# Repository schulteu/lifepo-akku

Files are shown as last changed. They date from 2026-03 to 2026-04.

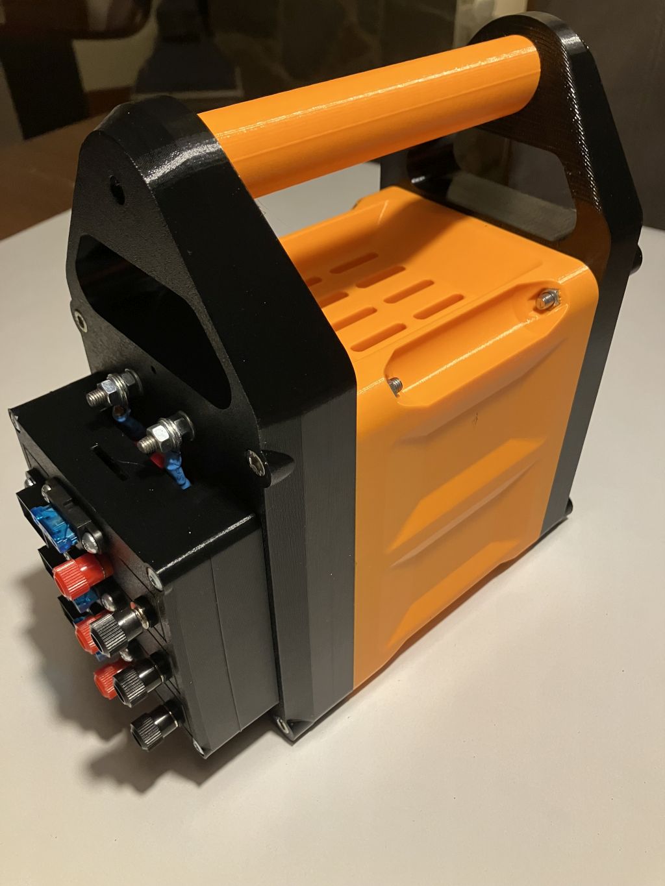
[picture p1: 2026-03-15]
Bilder/IMG_0235.JPG

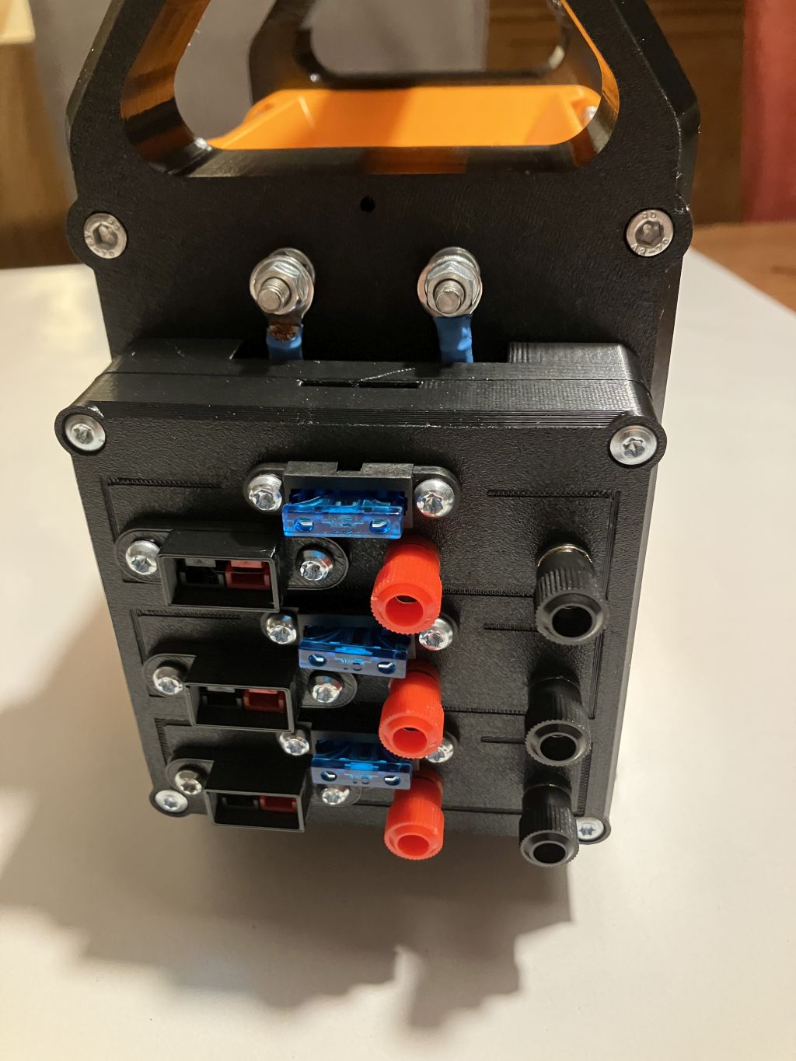
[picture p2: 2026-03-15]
Bilder/IMG_0234.JPG

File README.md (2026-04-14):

# LiFePo4-Akku 12V / 20Ah mit integriertem BMS – Selbstbauprojekt für Funk- und Notstrombetrieb

Dieser selbst gebaute LiFePo4-Akku besteht aus vier hochwertigen Rundzellen mit je 3,2V und 20Ah, die in Reihe geschaltet eine Nennspannung von 12,8V liefern. 

Mit einer Kapazität von 20Ah bietet er genug Energie für den stundenlangen Betrieb von Amateurfunkgeräten, Notfunkstationen oder anderen 12V-Verbrauchern – auch abseits der Steckdose.

Ein integriertes Batteriemanagementsystem (BMS) schützt die Zellen zuverlässig vor Überladung, Tiefentladung und Kurzschluss. Es überwacht Spannung und Temperatur jeder einzelnen Zelle und sorgt so für eine lange Lebensdauer und einen sicheren Betrieb. Das BMS ist per Bluetooth konfigurierbar und lässt sich bequem über eine Smartphone-App (iOS und Android) auslesen und einstellen.

Das kompakte Gehäuse wurde vollständig im 3D-Druck gefertigt und ist speziell auf die Anforderungen im Portabelbetrieb ausgelegt. Powerpole-Steckverbindungen sowie Bananenbuchsen ermöglichen einen schnellen und sicheren Anschluss an gängige Funkgeräte und Ladegeräte. Eine integrierte 50A-Hauptsicherung sowie drei separate 15A-Sicherungen für die einzelnen Abgänge sorgen für zusätzlichen Schutz.

Ob SOTA-Aktivierung, Notfunkübung oder einfach als portable Stromversorgung im Feld – dieser Akku ist ein zuverlässiger Begleiter überall dort, wo keine Netzversorgung zur Verfügung steht.
Technische Daten:

* Zellchemie: LiFePo4
* Zellkonfiguration: 4S1P (4 Zellen in Reihe)
* Nennspannung: 12,8V
* Kapazität: 20Ah (256Wh)
* Max. Entladestrom: 60A (Dauerstrom je nach BMS)
* BMS: Jikong mit Bluetooth-Anbindung
* Anschlüsse: Powerpole, 4mm-Bananenbuchsen
* Absicherung: 50A Hauptsicherung, 3x 15A
* Gehäuse: 3D-gedruckt (PLA/PETG)

**Anregung gerne an dl9uwe(at)darc.de**

# Lizenz:

„Dieses Design steht unter CC BY-NC-SA 4.0. Privater Nachbau und Modifikation sind ausdrücklich erlaubt. Eine kommerzielle Nutzung ist ohne ausdrückliche Genehmigung des Autors nicht gestattet."

# 12V / 20Ah LiFePo4 Battery with Integrated BMS – DIY Project for Radio and Emergency Power Applications

This DIY LiFePo4 battery consists of four high-quality cylindrical cells, each rated at 3.2V and 20Ah, which, when connected in series, deliver a nominal voltage of 12.8V.

With a capacity of 20Ah, it provides enough power for hours of operation of amateur radio equipment, emergency radio stations, or other 12V devices—even when away from a power outlet.

An integrated battery management system (BMS) reliably protects the cells against overcharging, deep discharge, and short circuits. It monitors the voltage and temperature of each individual cell, ensuring a long service life and safe operation. The BMS is configurable via Bluetooth and can be conveniently read and adjusted using a smartphone app (iOS and Android).

The compact housing was manufactured entirely via 3D printing and is specifically designed to meet the demands of portable use. Powerpole connectors and banana jacks enable quick and secure connection to standard radios and chargers. An integrated 50A main fuse and three separate 15A fuses for the individual outputs provide additional protection.

Whether for SOTA activations, emergency radio drills, or simply as a portable power source in the field—this battery is a reliable companion wherever mains power is unavailable. Technical Specifications:

* Cell chemistry: LiFePo4
* Cell configuration: 4S1P (4 cells in series)
* Nominal voltage: 12.8V
* Capacity: 20Ah (256Wh)
* Max. discharge current: 60A (continuous current depending on BMS)
* BMS: Jikong with Bluetooth connectivity
* Connections: Powerpole, 4mm banana jacks
* Fuses: 50A main fuse, 3x 15A
* Housing: 3D-printed (PLA/PETG)
* Feedback welcome at dl9uwe(at)darc.de

# License:

“This design is licensed under CC BY-NC-SA 4.0. Personal reproduction and modification are expressly permitted. Commercial use is not permitted without the author’s express permission.”

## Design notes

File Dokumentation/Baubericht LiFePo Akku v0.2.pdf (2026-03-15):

# Baubericht eines LiFePo4 Akkus

1

Version: 0.2 - Erstellt am: 25.01.2026 - Letzte Änderung siehe Fußzeile
15.03.2026 | Uwe Schultes, DL9UWE@darc.de (Draft) - Veröffentlichung der Dokumentation und der 3D-Druckdaten unter den Lizenzbedingungen: Creative Commons Lizenz: CC BY-NC-SA 4.0

15.03.2026 | Uwe Schultes, DL9UWE@darc.de (Draft) - Veröffentlichung der Dokumentation und der 3D-Druckdaten unter den
Lizenzbedingungen: Creative Commons Lizenz: CC BY-NC-SA 4.0 | 2

# Download

# via GitHub

# https://github.com/schulteu/lifepo-akku

15.03.2026 | 3

# Einleitung Ausschluss Haftung und Warnhinweis Technische Daten 3D Druckbauteile Werkzeug und Material Montage der Zellen Montage BMS Auflegen der Messleitungen Inbetriebnahme BMS

# Inhalt

# Montage der Temperaturfühler Zusammenbau der Anschlussbox Zusammenbau Gehäuse Inbetriebnahme BMS

Uwe Schultes, DL9UWE@darc.de (Draft) - Veröffentlichung der Dokumentation und der 3D-Druckdaten unter den

# Einleitung

# Einleitung

# Die Idee zu dem LiFePo Akku ist an einem Bastelabends während einer

Diskussion mit einigen Funkamateuren im G11 (Leverkusen) entstanden.

# Ein Funkamateur hat darüber berichtet, wie er Akkus für seine PV- Anlage

selbst zusammenstellt.
Die Preise des Lieferanten haben uns damals neugierig gemacht.

# Bei der Durchsicht des Portfolios des Lieferanten ist uns eine sehr

günstige Rundzelle mit 3,2V/20Ah aufgefallen.

# Vier von diesen Rundzellen in Serie geschaltet, ergeben 12-13 Volt ist

# genau dass, was der Funkamateur für den Outdoor- und Notfunkbetrieb

benötigt.

# Ausschluss und Warnhinweis

# Es wird jegliche Haftung beim Zusammenbau ausgeschlossen!

# Warnhinweis

# Beim Umgang mit Lithium-Eisenphosphat-Zellen und elektrischen

Komponenten ist besondere Vorsicht geboten.

# Unsachgemäßer Umgang kann zu Kurzschlüssen, Bränden oder

Verletzungen führen.
Es fließen bei diesem Akku im Fall eines Kurzschlusses bis zu 60A (!).

# Das kann dazu führen, dass die Anschlüsse regelrecht verschweißt

und nicht mehr gelöst werden können.

# Prüfe bitte alle Verbindungen sorgfältig, bevor du den Akku in Betrieb

nimmst.

# Technische Daten

# Technische Daten der LiFePo4 Zelle

LiFePo4-Zellen mit 3,2V und 20Ah.

# Die Zelle wird mit 2 Muttern und einer Verbindungsbrücke

geliefert, mit der weitere Zellen verbunden werden können.

## ✓LiFePo4 Rundzelle 3,2V mit 20Ah ✓Entladestrom: 60A ✓Höhe: 140 mm ✓Dicke: x 40.8 mm

✓Gewicht je Zelle: 374gr.

# Lieferant: nkon (Niederland)

EVE C40 40135 (https://www.nkon.nl/de/eve-c40-40135-20ah-3-2v.html) - 20Ah (https://www.nkon.nl/de/eve-c40-40135-20ah-3-2v.html) - 60A LiFePO4 (https://www.nkon.nl/de/eve-c40-40135-20ah-3-2v.html) - 3.2V (https://www.nkon.nl/de/eve-c40-40135-20ah-3-2v.html) - A- (https://www.nkon.nl/de/eve-c40-40135-20ah-3-2v.html)grade (https://www.nkon.nl/de/eve-c40-40135-20ah-3-2v.html)

15.03.2026 | 10 Uwe Schultes, DL9UWE@darc.de (Draft) - Veröffentlichung der Dokumentation und der 3D-Druckdaten unter den

# Technische Daten des BMS

# Jikong BD6A8S10P (alt)

## ✓Smartphone App verfügbar (Apple und Android) ✓Bis 8 Zellen in Serie ✓Bis 10 Zellen Parallel ✓Via Bluetooth konfigurierbar

# Jikong B1A8S10P (neu) Lieferant: AliExpress

15.03.2026 | 11 Uwe Schultes, DL9UWE@darc.de (Draft) - Veröffentlichung der Dokumentation und der 3D-Druckdaten unter den

# 3D Druckbauteile

15.03.2026 | 12 Uwe Schultes, DL9UWE@darc.de (Draft) - Veröffentlichung der Dokumentation und der 3D-Druckdaten unter den

# Innenteil (Vorne)

# Das Bauteil ist im Inneren des Akkus und sorgt dafür, dass die 4 Akkus und das BMS miteinander verschraubt sind und das BMS mit den Akkus

verkabelt werden kann.

# Es gibt ein Bauteil mit der Bezeichnung „Vorne“

und ein Bauteil mit der Bezeichnung „Hinten“.

# Die Anschlüsse sind auch entsprechend gekennzeichnet, so das der Aufbau vereinfacht

wird.

15.03.2026 | 13 Uwe Schultes, DL9UWE@darc.de (Draft) - Veröffentlichung der Dokumentation und der 3D-Druckdaten unter den

# Innenteil (Hinten)

# Das Bauteil ist im Inneren des Akkus und sorgt dafür, dass die 4 Akkus und das BMS miteinander verschraubt sind und das BMS mit den Akkus

verkabelt werden kann.

# Es gibt ein Bauteil mit der Bezeichnung „Vorne“

und ein Bauteil mit der Bezeichnung „Hinten“.

# Die Anschlüsse sind auch entsprechend gekennzeichnet, so das der Aufbau vereinfacht

wird.

15.03.2026 | 14 Uwe Schultes, DL9UWE@darc.de (Draft) - Veröffentlichung der Dokumentation und der 3D-Druckdaten unter den

# Verstrebung Innenteil

# Diese Verstrebung wird für die Fixierung der

Temperatursensoren gebraucht.

Es gibt 2 Temperatursensoren.

# Für jeden Temperatursensor wird jeweils eine

Verstrebung seitlich am Akkublock angebracht.

# Und mit jeweils 2 x Schrauben Tx 3,5 mm x 16

mm verschraubt.

15.03.2026 | 15 Uwe Schultes, DL9UWE@darc.de (Draft) - Veröffentlichung der Dokumentation und der 3D-Druckdaten unter den

# Seitenteil mit Schalter

Die äußere Einheit besteht aus 2 Seitenteilen.

# Dieses Seitenteil ist dafür vorgesehen, den Ein/Ausschalter des BMS

aufzunehmen.

15.03.2026 | 16 Uwe Schultes, DL9UWE@darc.de (Draft) - Veröffentlichung der Dokumentation und der 3D-Druckdaten unter den

# Seitenteil mit Durchbruch

Die äußere Einheit besteht aus 2 Seitenteilen.

# Dieses Seitenteil ist dafür vorgesehen, die Anschlussbox seitlich

aufzunehmen.

15.03.2026 | 17 Uwe Schultes, DL9UWE@darc.de (Draft) - Veröffentlichung der Dokumentation und der 3D-Druckdaten unter den

# Anschlussbox

Die Anschlussbox wird auf das Seitenteil mit dem Durchbruch montiert.

# Hier werden die Powerpole-Steckverbindungen, die Bananenbuchsen und die

KFZ-Stecksicherungen montiert.
Zur Montage der Bauteile gibt es zusätzliche Adapter.

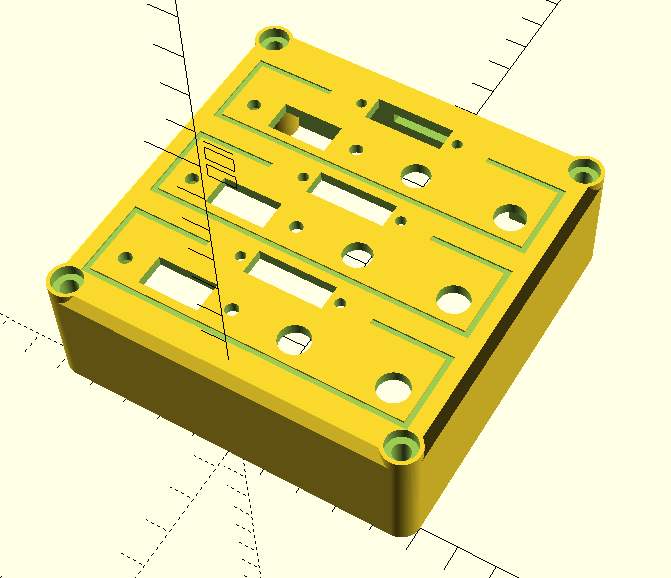
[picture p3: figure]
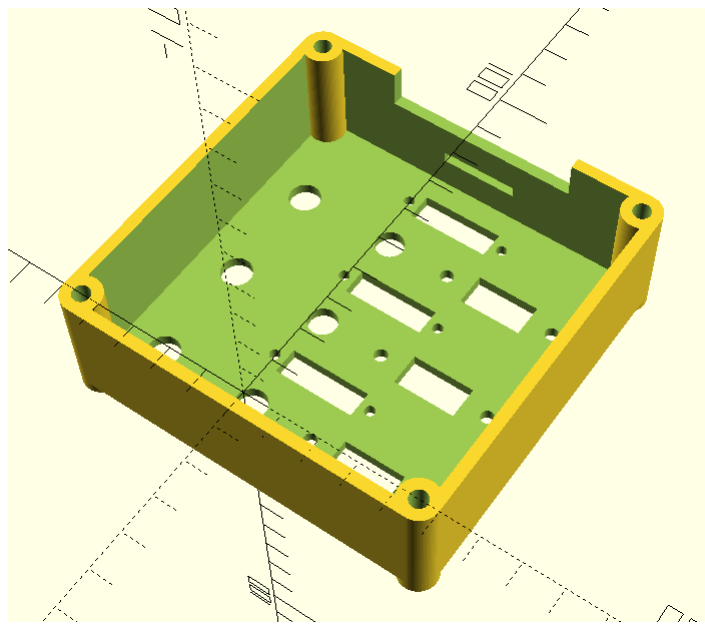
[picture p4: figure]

15.03.2026 | 18 Uwe Schultes, DL9UWE@darc.de (Draft) - Veröffentlichung der Dokumentation und der 3D-Druckdaten unter den

# Mittelteil Aussen

# Das Gehäuse an dem rechts und links die

Seitenteile verschraubt werden.

# Oben auf dem Gehäuse sind

Lüftungsschlitze angebracht.

# Die Verschraubung erfolgt mittels

metrischer Inbusschrauben M5 x 40.

# Dazu werden in das Gehäuse M5 Muttern

eingepresst.

15.03.2026 | 19 Uwe Schultes, DL9UWE@darc.de (Draft) - Veröffentlichung der Dokumentation und der 3D-Druckdaten unter den

# Powerpole Einsatz

Dieser Adapter nimmt die Powerpole Steckverbindung auf.

# Zusammen mit dem Clip kann der Powerpole Adapter in

der Anschlussbox montiert werden.

# Der Clip wird nach Montage der Powerpole-

Steckverbindung auf den Powerpole Einsatz „aufgeclipt“. Dadurch ist die Powerpole-Steckverbindung fixiert.

# Der Adapter wird auf der Oberseite der Anschlussbox montiert und macht es bei Anwendung des Akkus etwas

leichter die Powerpole Steckverbindungen einzuführen.

15.03.2026 | 20 Uwe Schultes, DL9UWE@darc.de (Draft) - Veröffentlichung der Dokumentation und der 3D-Druckdaten unter den

# Griff

Der Tragegriff für den Akku.

# Er wird in die Griffmulden der Seitenteile eingeführt und zusätzlich mit Torx Blechschrauben M3,5 x 16 mm

verschraubt.

15.03.2026 | 21 Uwe Schultes, DL9UWE@darc.de (Draft) - Veröffentlichung der Dokumentation und der 3D-Druckdaten unter den

# Distanzstücke Bananenbuchsen

# Die Distanzstücke werden bei der Montage der

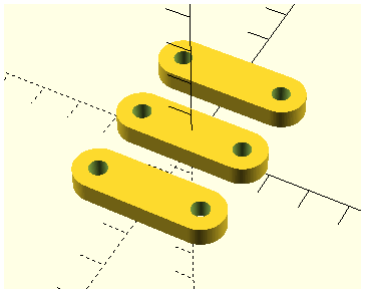
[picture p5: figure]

Bananenbuchsen in der Anschlussbox gebraucht.

# Die mitgelieferten originalen Rundhülsen sind nicht besonders stabil, wenn die Bananenbuchsen fest

verschraubt werden.

# Daher werden diese Hülsen nicht genutzt und gegen

die Distanzstücke getauscht.

15.03.2026 | 22 Uwe Schultes, DL9UWE@darc.de (Draft) - Veröffentlichung der Dokumentation und der 3D-Druckdaten unter den

# Abdeckung Hauptsicherung

# Die 50A Hochstromsicherung ist von außen zugänglich und wird durch eine Abdeckung

geschützt.

# Ein Austausch ist so leicht möglich, ohne das Gerät

selbst zu öffnen.

15.03.2026 | 23 Uwe Schultes, DL9UWE@darc.de (Draft) - Veröffentlichung der Dokumentation und der 3D-Druckdaten unter den

# Abdeckkappen

# Kappen bzw. Abdeckung für die

Schraubanschlüsse der Akkus.

15.03.2026 | 24 Uwe Schultes, DL9UWE@darc.de (Draft) - Veröffentlichung der Dokumentation und der 3D-Druckdaten unter den

# Abdeckung Anschlüsse BMS

# Die Abdeckung sorgt für eine Isolation

zwischen den Ringösen und dem BMS.

15.03.2026 | 25 Uwe Schultes, DL9UWE@darc.de (Draft) - Veröffentlichung der Dokumentation und der 3D-Druckdaten unter den

# Werkzeug und Material

15.03.2026 | 26 Uwe Schultes, DL9UWE@darc.de (Draft) - Veröffentlichung der Dokumentation und der 3D-Druckdaten unter den

# Werkzeug und Material

# Seitenschneider oder Kabelzange Abisolierzange Multimeter Schraubendreher (Torx) Maul-, Ring oder Steckschlüssel SW10

# Heißluftföhn, alternativ ein Feuerzeug (für Schrumpfschlauch) Crimpzangen

## ✓für Powerpole Stecker ✓für Ringösen und Kabelschuhe

15.03.2026 | 27 Uwe Schultes, DL9UWE@darc.de (Draft) - Veröffentlichung der Dokumentation und der 3D-Druckdaten unter den

# Material

# Ringösen

## ✓6 x 4 mm für 1,5 mm²

## (rot) bis 2,5 mm²

## (blau) ✓6 x 6 mm für 1,5 mm²

## (rot) bis 2,5 mm²

## (blau) ✓4 x 6 mm für 6 mm²

# Kabelschuhe

## ✓3 x 4,8 mm für 1,5 mm²

# Litze

## ✓ca. 1 m schwarz 1,5 mm² bis 2,5 mm² ✓ca. 1 m rot 1,5 mm² bis 2,5 mm² ✓ca. 30 cm schwarz 6 mm²

# Material

# Blechschrauben

## ✓14 x Torx 3,5 mm x 16 mm ✓1 x Torx 3,5 mm x 30 mm ✓4 x Torx 3,5 mm x 40 mm

# Schrauben

## ✓2 x Sechskant M5 x 16 ✓4 x Inbus M5 x 40 mm ✓Inbus M6 x 16 mm

# Muttern

✓6 x M5

# Scheiben

## ✓6 x 5 mm ✓8 x 8 mm

# Montage Zellen

15.03.2026 | 30 Uwe Schultes, DL9UWE@darc.de (Draft) - Veröffentlichung der Dokumentation und der 3D-Druckdaten unter den

# Montage der Zellen

# Achtung, die schwarze Seite, isolierte der Zelle ist der Minuspol der Zelle!

Darauf achten wenn die Zellen in die Innenteile geschraubt werden.

# Der Pluspol liegt am Gehäuse der Zelle!

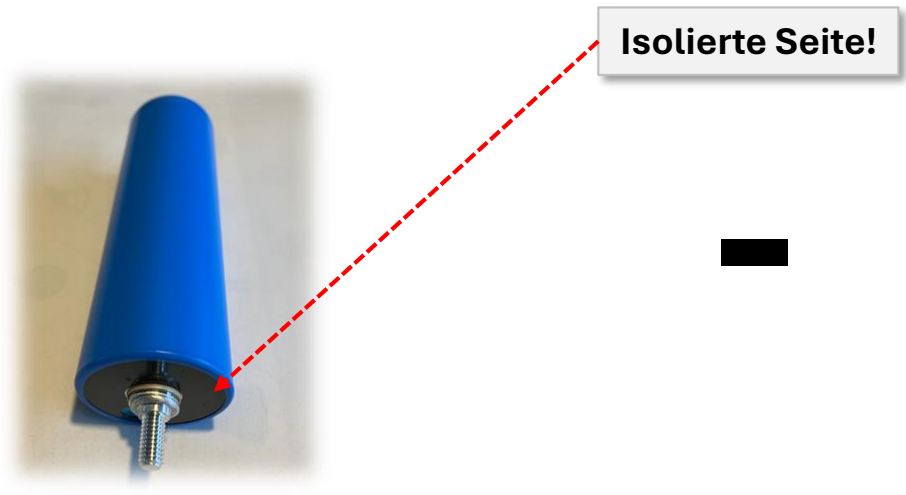
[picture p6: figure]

# Montage der Zellen

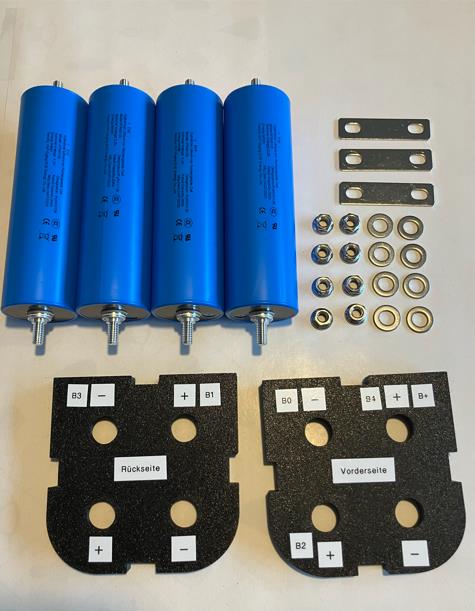
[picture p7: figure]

# Was brauchen wir?

# ✓4 x Zellen ✓3 x Brücken ✓8 x 6mm Schrauben ✓8 x 8mm Unterlegscheiben ✓2 x Innenteile (vorne und Hinten)

# Hinweis: die neuen Seitenteile müssen für den Aufbau nicht mehr beschriftet werden, die Bezeichnung ist bei neuen Druckteilen eingeprägt!

# Montage der Zellen

# Die Zellen werden mit den beiden Innenteilen und den beigelegten M6 Muttern

verschraubt.
Dazu wird zusätzliche eine 8 mm Unterlegscheibe benötigt.

# Auf den Innenteilen ist die Polung angegeben. Es ist darauf zu achten, dass die

Polung der Zellen stimmt, damit wird der weitere Aufbau vereinfacht.

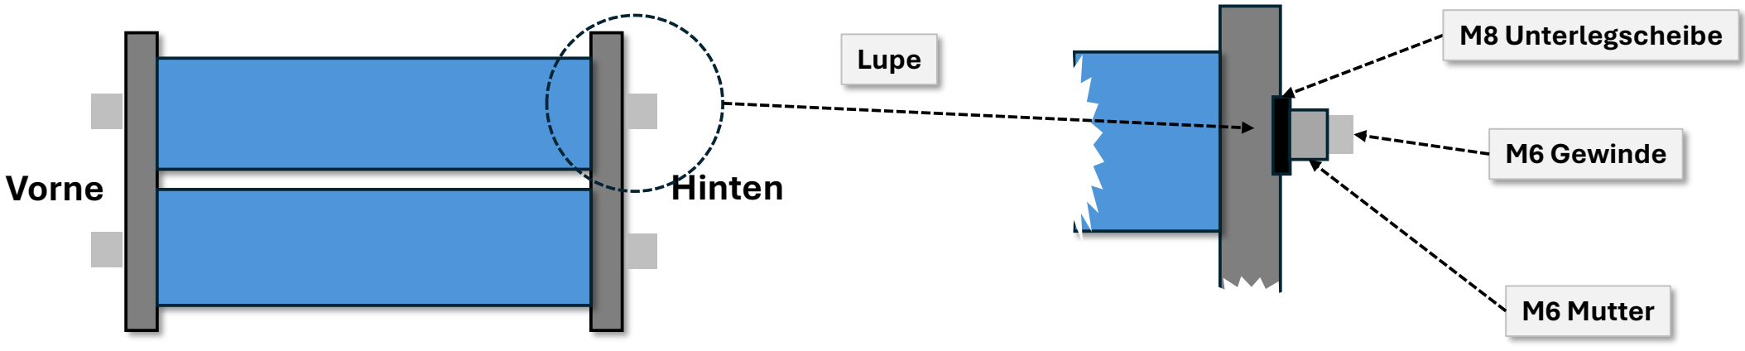
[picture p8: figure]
Vorne; Hinten; M8 Unterlegscheibe; M6 Mutter; M6 Gewinde; Lupe

# Montage der Zellen

# Die Muttern werden erstmal nur „Handfest“ verschraubt, da später die

Ringösen von dem BMS später montiert werden.

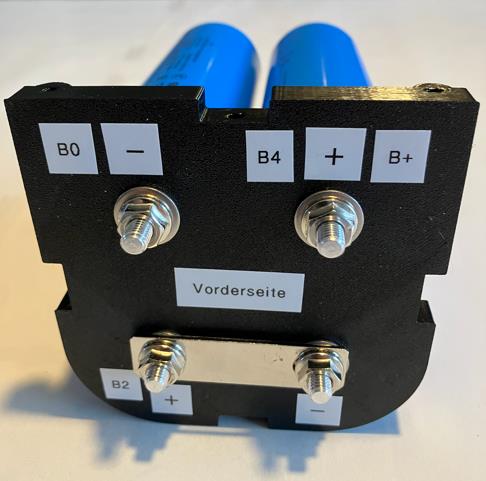
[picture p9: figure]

15.03.2026 | 34 Uwe Schultes, DL9UWE@darc.de (Draft) - Veröffentlichung der Dokumentation und der 3D-Druckdaten unter den

# Montage der Zellen

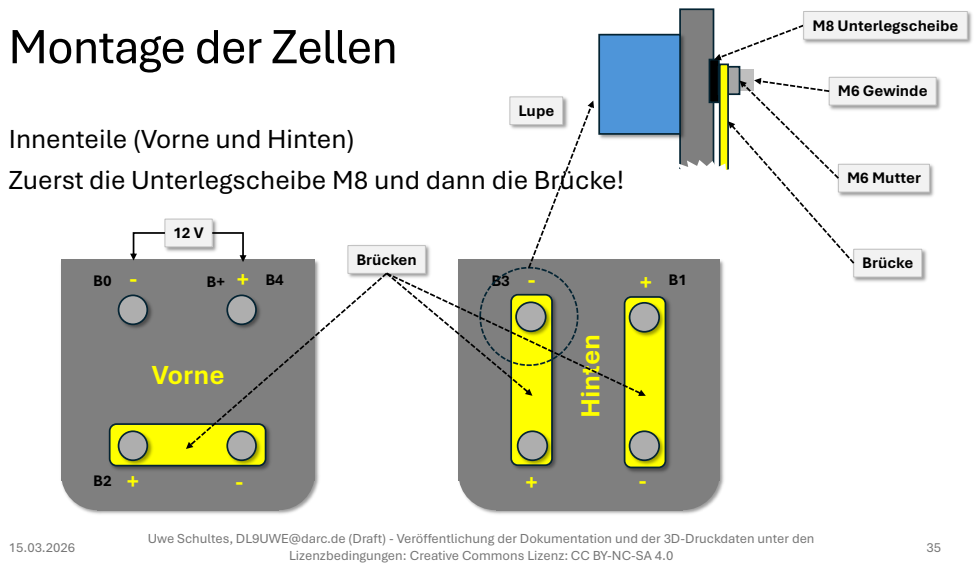
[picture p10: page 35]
Brücken; Vorne; Hinten; M8 Unterlegscheibe; M6 Mutter; M6 Gewinde; Brücke; Lupe

Innenteile (Vorne und Hinten)
Zuerst die Unterlegscheibe M8 und dann die Brücke!

# Montage BMS

15.03.2026 | 36 Uwe Schultes, DL9UWE@darc.de (Draft) - Veröffentlichung der Dokumentation und der 3D-Druckdaten unter den

# Montage BMS

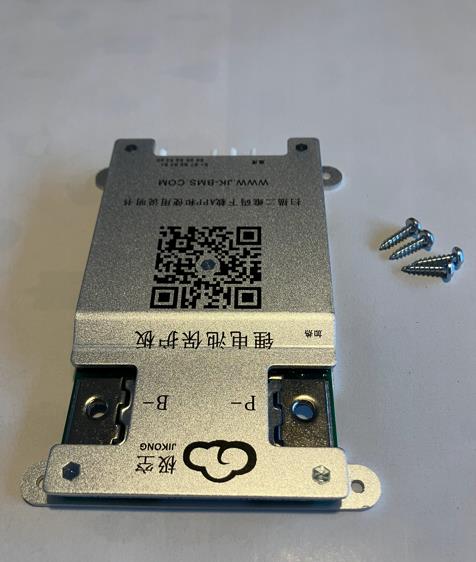
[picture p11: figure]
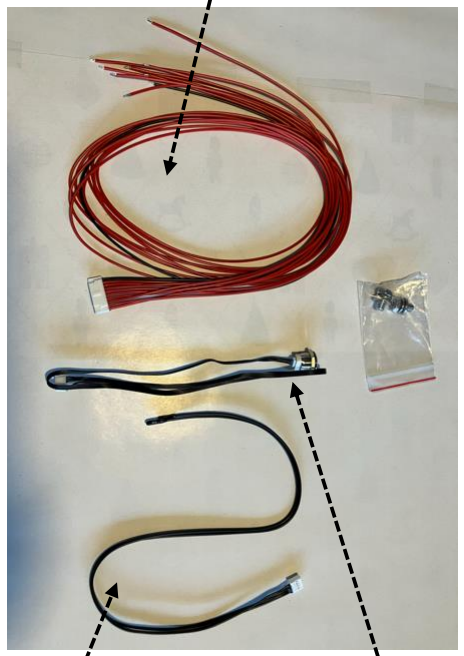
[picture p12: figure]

# Was wird gebraucht?

## ✓BMS ✓4 x Blechschrauben Torx 3,5 mm x 16 mm

Messleitungen

Temperaturfühler | Schalter

# Montage BMS

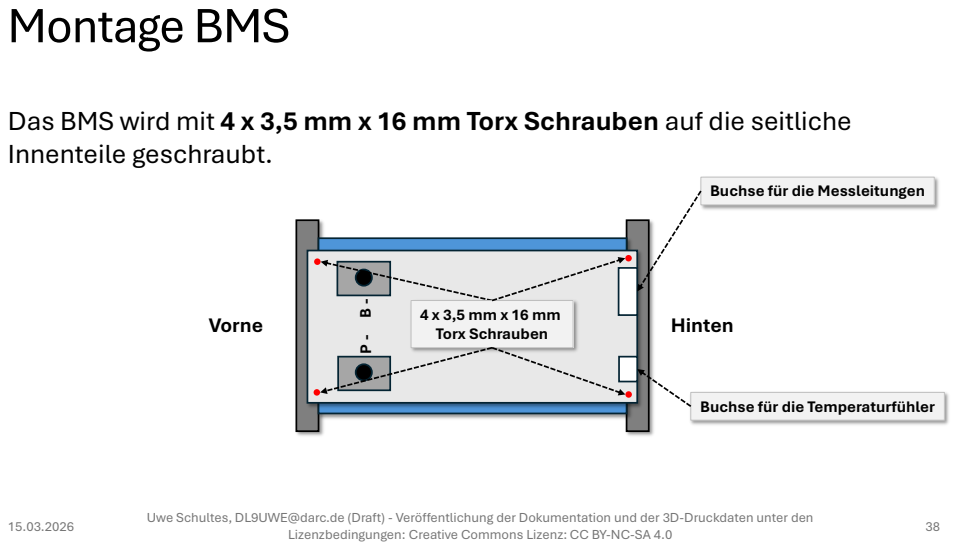
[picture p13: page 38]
Vorne; Hinten; 4 x 3,5 mm x 16 mm Torx Schrauben

Das BMS wird mit 4 x 3,5 mm x 16 mm Torx Schrauben auf die seitliche
Innenteile geschraubt.

Buchse für die Messleitungen

Buchse für die Temperaturfühler

# Montage BMS

# - Ansicht Vorne und Hinten

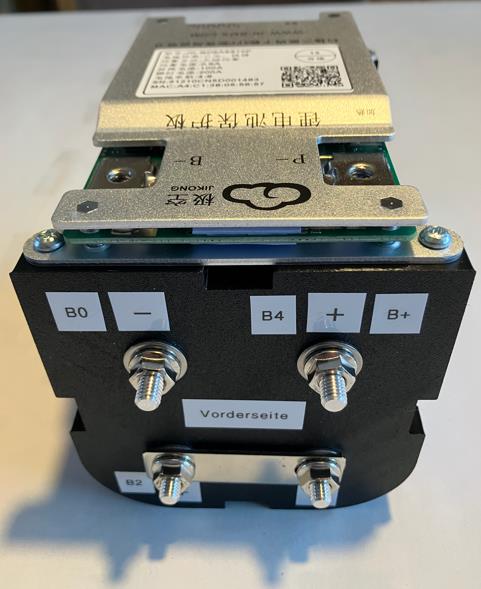
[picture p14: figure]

15.03.2026 | 39 Uwe Schultes, DL9UWE@darc.de (Draft) - Veröffentlichung der Dokumentation und der 3D-Druckdaten unter den

# Auflegen der Messleitungen

15.03.2026 | 40 Uwe Schultes, DL9UWE@darc.de (Draft) - Veröffentlichung der Dokumentation und der 3D-Druckdaten unter den

# Auflegen der Messleitungen

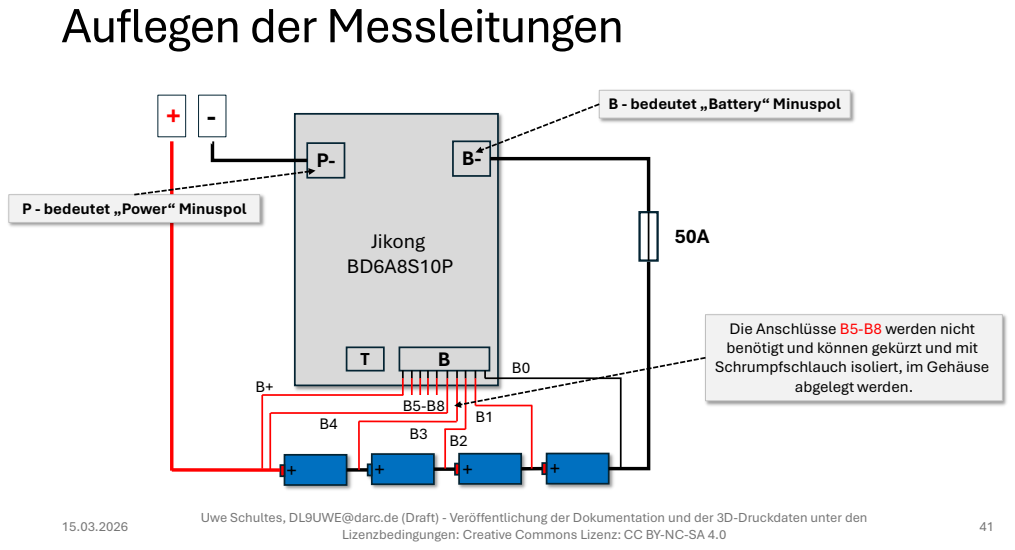
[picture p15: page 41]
Jikong BD6A8S10P; abgelegt werden.

B - bedeutet „Battery“ Minuspol

P - bedeutet „Power“ Minuspol

Die Anschlüsse B5-B8 werden nicht
benötigt und können gekürzt und mit
Schrumpfschlauch isoliert, im Gehäuse

# Auflegen der Messleitungen

# Was wird gebraucht?

## ✓Messleitungen ✓6 x 5 mm Ringösen

15.03.2026 | 42 Uwe Schultes, DL9UWE@darc.de (Draft) - Veröffentlichung der Dokumentation und der 3D-Druckdaten unter den

# Auflegen der Messleitungen

# Die Messleitungen sind eigentlich für die Ringösen bei einem

Durchmesser der Ösen von 6 mm zu dünn.

# Die Empfehlung: Kabel ca. 3 cm abzuisolieren, zu falten

und erst dann zu crimpen.

# Alternativ können die Messleitungen auch mit den Ösen

verlötet werden.

Anschließend mit Schrumpfschlauch isolieren.

3 cm

# Auflegen der Messleitungen

# Gefaltete Leitung

## Achtung: vor dem Crimpen unbedingt den Schrumpfschlauch aufziehen!!

# Auflegen der Messleitungen

# Ader gecrimpt

15.03.2026 | 45 Uwe Schultes, DL9UWE@darc.de (Draft) - Veröffentlichung der Dokumentation und der 3D-Druckdaten unter den

# Auflegen der Messleitungen

# Ader fertig gecrimpt

15.03.2026 | 46 Uwe Schultes, DL9UWE@darc.de (Draft) - Veröffentlichung der Dokumentation und der 3D-Druckdaten unter den

# Messleitungen auflegen

# Auflegen der Messleitungen

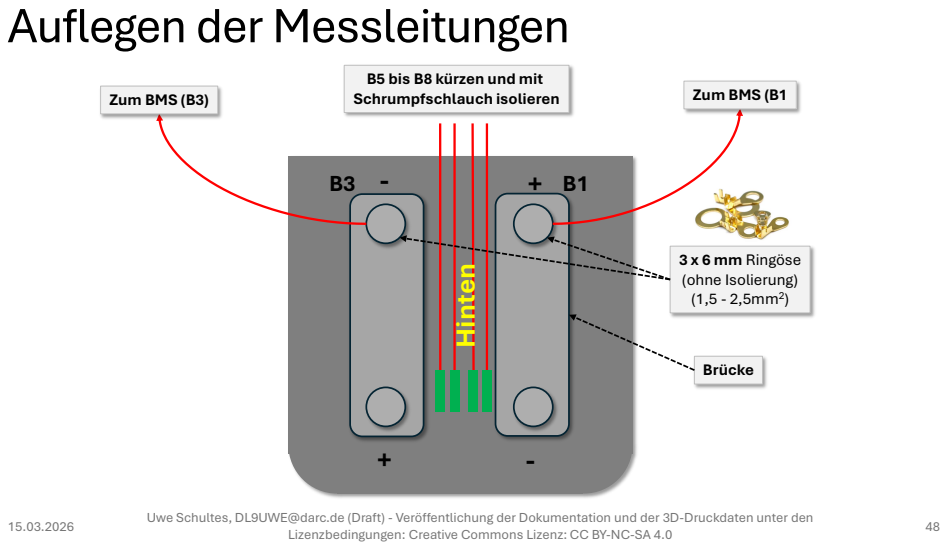
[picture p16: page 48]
Brücke; 3 x 6 mm Ringöse (ohne Isolierung) (1,5 - 2,5mm²; Zum BMS (B3); Zum BMS (B1; 48 Hinten

B5 bis B8 kürzen und mit
Schrumpfschlauch isolieren

# Auflegen der Messleitungen

B0 | B1

B2

# Auflegen der Messleitungen

B3

B4 | B+

# Auflegen der Messleitungen

# Die Adern von B5 bis B8 werden nicht benötigt, eingekürzt und mit Schrumpfschlauch geschützt und mit Kabelbinder fixiert

15.03.2026 | 51 Uwe Schultes, DL9UWE@darc.de (Draft) - Veröffentlichung der Dokumentation und der 3D-Druckdaten unter den

# Montage Temperaturfühler

15.03.2026 | 52 Uwe Schultes, DL9UWE@darc.de (Draft) - Veröffentlichung der Dokumentation und der 3D-Druckdaten unter den

# Montage Temperaturfühler

# Was brauchen wir dafür?

## ✓2 x Temperaturfühler ✓2 x Verstrebungen ✓2 x Blechschraube 3,5 mm x 16 mm ✓3 x Kabelbinder

15.03.2026 | 53 Uwe Schultes, DL9UWE@darc.de (Draft) - Veröffentlichung der Dokumentation und der 3D-Druckdaten unter den

# Montage Temperaturfühler

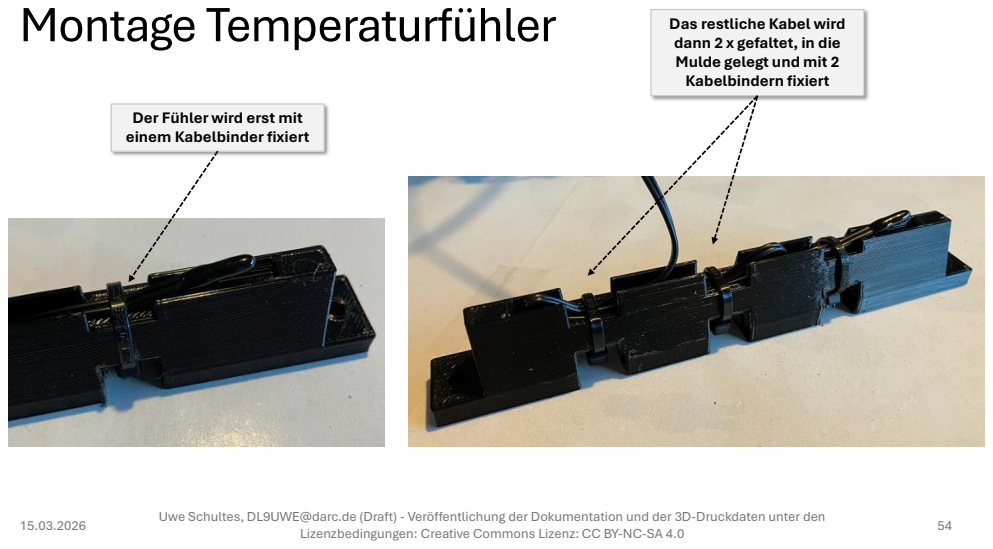
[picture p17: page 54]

Das restliche Kabel wird
dann 2 x gefaltet, in die
Mulde gelegt und mit 2
Kabelbindern fixiert

Der Fühler wird erst mit
einem Kabelbinder fixiert

# Montage Temperaturfühler

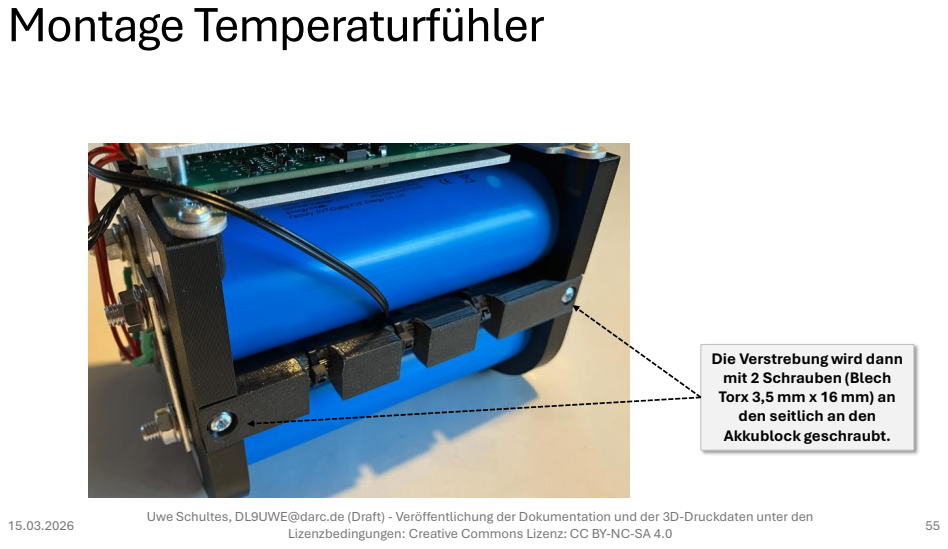
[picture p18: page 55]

Die Verstrebung wird dann
mit 2 Schrauben (Blech
Torx 3,5 mm x 16 mm) an
den seitlich an den
Akkublock geschraubt.

# Zusammenbau Anschlussbox

15.03.2026 | 56 Uwe Schultes, DL9UWE@darc.de (Draft) - Veröffentlichung der Dokumentation und der 3D-Druckdaten unter den

# Zusammenbau Anschlussbox

# Was brauchen wir? ✓1 x Anschlussbox ✓3 x Clips für Powerpole ✓3 x Bananenbuchse rot ✓3 x Bananenbuchse schwarz ✓12 x Blech Torx 3,5 mm x 16 mm ✓3 x 15 A Sicherungen ✓3 x Sicherungshalter

15.03.2026 | 57 Uwe Schultes, DL9UWE@darc.de (Draft) - Veröffentlichung der Dokumentation und der 3D-Druckdaten unter den

# Zusammenbau Anschlussbox

Die beiden Powerpole Steckverbindungen müssen
zunächst ineinander geschoben werden.
Achtung! Bitte genauso so wie auf den Bildern
zusammenbauen.
Links rot, rechts schwarz und die beiden Nasen der
Powerpole Steckverbindungen zeigen nach unten.
In dem Adapter selbst sind 2 weitere Führungslippen,
die genau in Einbuchtungen der Powerpole
Steckverbindungen passen.
Dadurch werden die Steckverbindungen in dem Clip fest
verankert.

# Zusammenbau Anschlussbox

2

1
3

Führungslippen

# Zusammenbau Anschlussbox

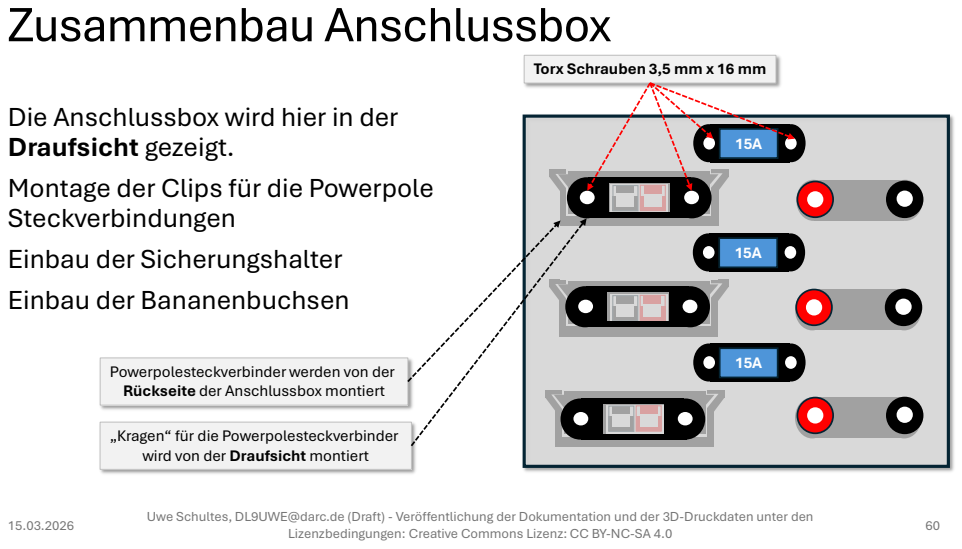
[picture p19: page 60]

Torx Schrauben 3,5 mm x 16 mm

Die Anschlussbox wird hier in der
Draufsicht gezeigt.
Montage der Clips für die Powerpole
Steckverbindungen
Einbau der Sicherungshalter
Einbau der Bananenbuchsen

Powerpolesteckverbinder werden von der
Rückseite der Anschlussbox montiert

„Kragen“ für die Powerpolesteckverbinder
wird von der Draufsicht montiert

# Zusammenbau Anschlussbox

Rückseite | Draufsicht

# Zusammenbau Anschlussbox

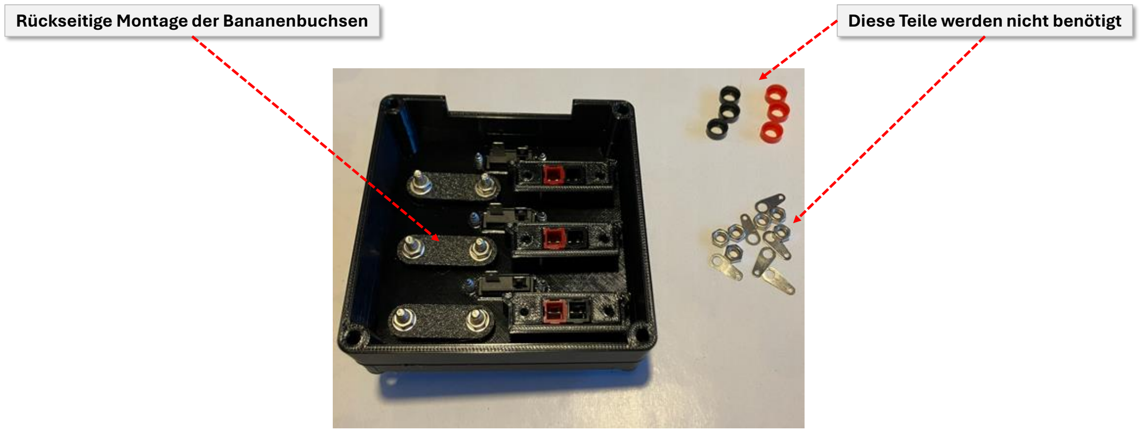
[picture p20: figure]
Rückseitige Montage der Bananenbuchsen; Diese Teile werden nicht benötigt

# Zusammenbau Anschlussbox

# Kabelquerschnitt 1,5 mm

# Zusammenbau Anschlussbox

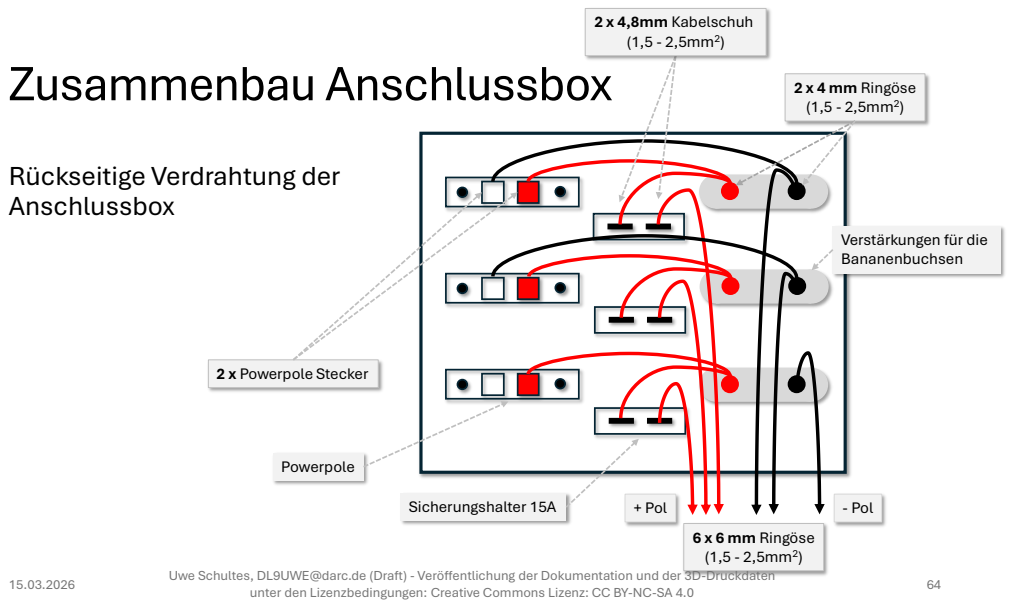
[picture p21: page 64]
+ Pol; - Pol; Powerpole; Sicherungshalter 15A; 2 x 4 mm Ringöse (1,5 - 2,5mm²; 2 x 4,8mm Kabelschuh (1,5 - 2,5mm²; 6 x 6 mm Ringöse (1,5 - 2,5mm²; 2 x Powerpole Stecker

Rückseitige Verdrahtung der
Anschlussbox

Verstärkungen für die
Bananenbuchsen

Uwe Schultes, DL9UWE@darc.de (Draft) - Veröffentlichung der Dokumentation und der 3D-Druckdaten

unter den Lizenzbedingungen: Creative Commons Lizenz: CC BY-NC-SA 4.0

# Zusammenbau Anschluss

Rückseitige Verdrahtung Seitenteil mit
Anschlussbox

Die beiden Leitungen, die von der
Sicherung kommen und jeweils
zum Anschluss B- und zu dem
Minuspol des BMS führen

3 Leitungen die zum Anschluss P-
auf dem BMS führen

3 Leitungen die zum Anschluss +
am Akku führen

Die Bananenbuchse ist Stützpunkt für jeweils 2 Leitungen

# Zusammenbau Anschlussbox

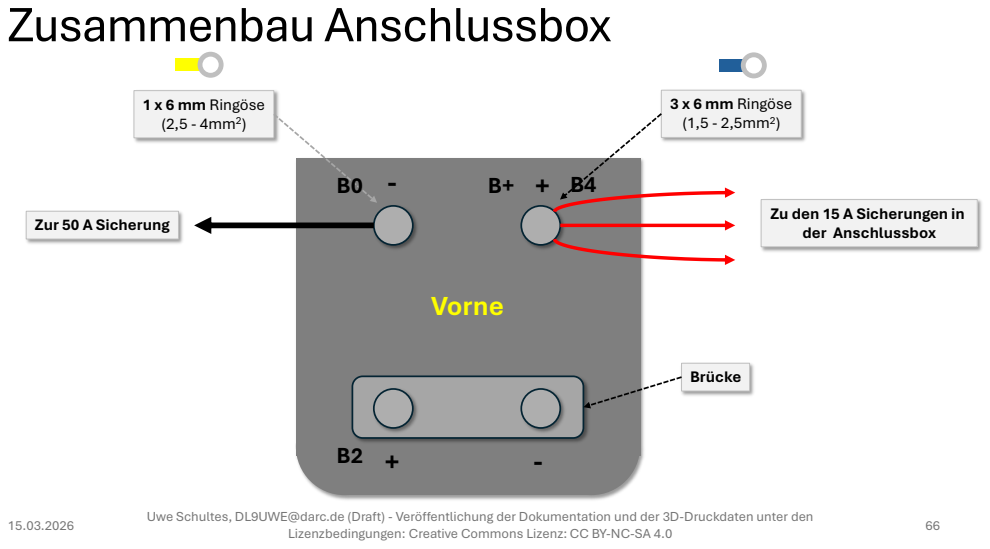
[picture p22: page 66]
Vorne; Brücke; 3 x 6 mm Ringöse (1,5 - 2,5mm²; 1 x 6 mm Ringöse (2,5 - 4mm²; Zur 50 A Sicherung

Zu den 15 A Sicherungen in
der Anschlussbox

# Zusammenbau Gehäuse

15.03.2026 | 67 Uwe Schultes, DL9UWE@darc.de (Draft) - Veröffentlichung der Dokumentation und der 3D-Druckdaten unter den

# Zusammenbau Gehäuse

Schalter hier montieren

Einbau des Schalters im Seitenteil.
Das Seitenteil wird über 4
Inbusschrauben mit dem Mittelteil
verschraubt.

# Zusammenbau Gehäuse

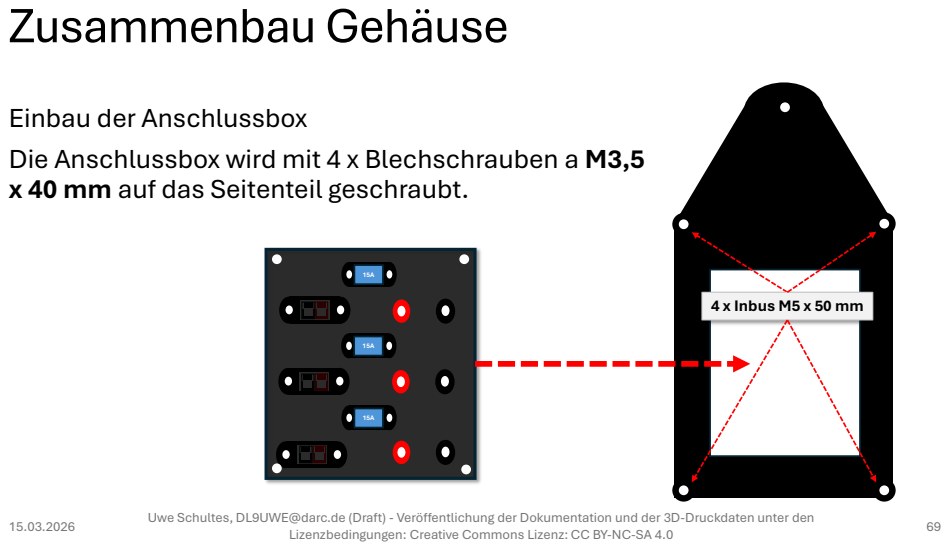
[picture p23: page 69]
4 x Inbus M5 x 50 mm

Einbau der Anschlussbox
Die Anschlussbox wird mit 4 x Blechschrauben a M3,5
x 40 mm auf das Seitenteil geschraubt.

# Montage der der Sicherung

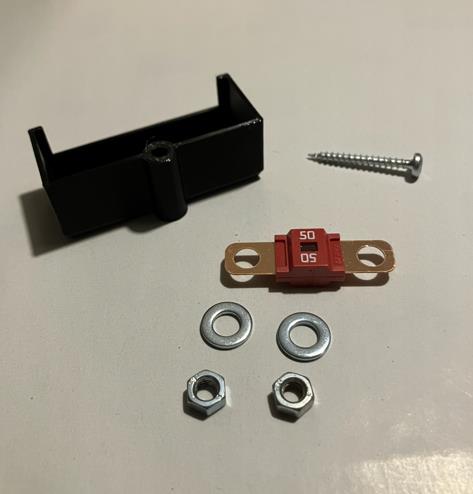
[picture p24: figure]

# Was wird gebraucht? ✓Abdeckung 50A Sicherung ✓50A Sicherung ✓Blechschraube 3,5 mm x 30 mm ✓6 x Mutter M5 ✓6 x Unterlegscheibe M5

# Zusammenbau Gehäuse

15.03.2026 | 70 Uwe Schultes, DL9UWE@darc.de (Draft) - Veröffentlichung der Dokumentation und der 3D-Druckdaten unter den

# Zusammenbau Gehäuse

# Kabelquerschnitt 6 mm² für die Zuleitung Hauptsicherung +BMS

2 x | 15 cm
5 mm Ringöse | 6 mm Ringöse

# Zusammenbau Gehäuse

Verdrahtung und Anschluss der 50 A
Hauptsicherung

50

# Zusammenbau Gehäuse

# Verdrahtung B- und P-

# Achtung: In der neuen Version

# gibt es bereits ein weiteres

Druckbauteil, das verhindert,

# das die Ringösen das Blechteil

vom BMS berühren können.

# Zusammenbau Gehäuse

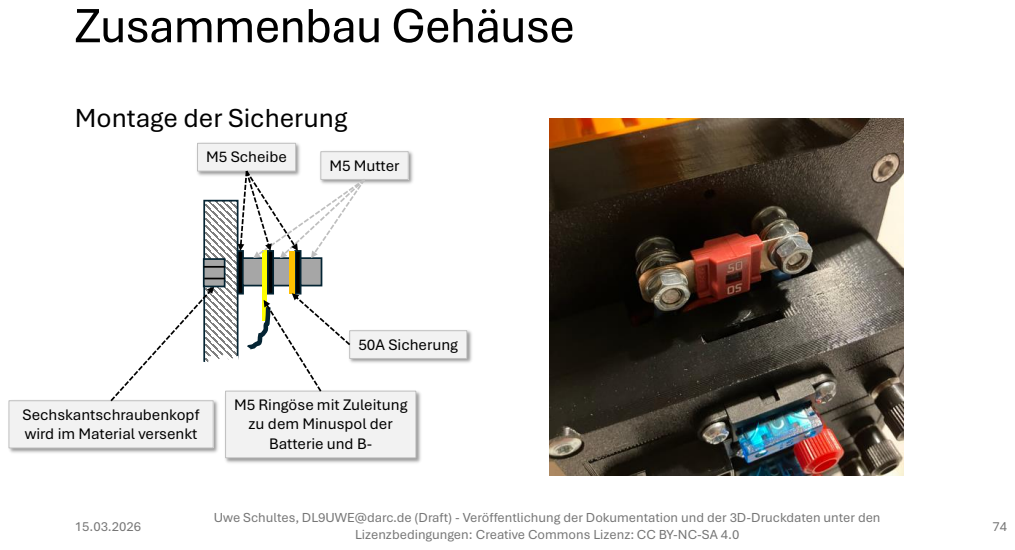
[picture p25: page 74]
M5 Mutter M5 Scheibe; 50A Sicherung

Montage der Sicherung

M5 Ringöse mit Zuleitung
zu dem Minuspol der
Batterie und B-

Sechskantschraubenkopf
wird im Material versenkt

# Zusammenbau Gehäuse

# Montierte Anschlussbox und Abdeckung

15.03.2026 | 75 Uwe Schultes, DL9UWE@darc.de (Draft) - Veröffentlichung der Dokumentation und der 3D-Druckdaten unter den

# Zusammenbau Gehäuse

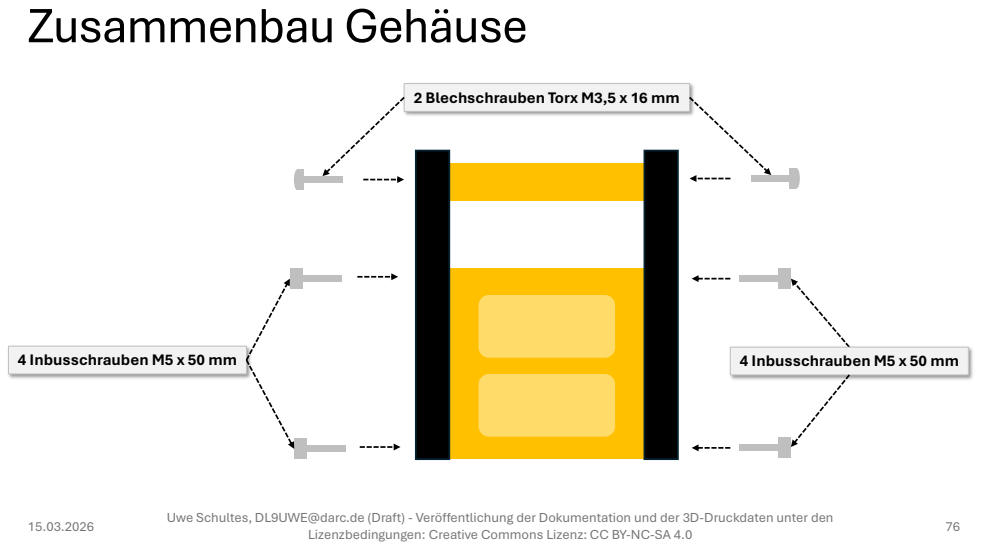
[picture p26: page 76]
4 Inbusschrauben M5 x 50 mm

2 Blechschrauben Torx M3,5 x 16 mm

# Inbetriebnahme BMS

15.03.2026 | 77 Uwe Schultes, DL9UWE@darc.de (Draft) - Veröffentlichung der Dokumentation und der 3D-Druckdaten unter den

# Download der Software

# Apple und Android

## to be defined…

# Grundkonfiguration

# - Wird das BMS eingeschaltet, ist das BMS via Bluetooth sofort in der Applikation mit der Hardware ID sichtbar

und kann dort zur Konfiguration ausgewählt werden.
- Dazu ist „Settings“ auszuwählen.
- Das Standardpasswort ist „123456“.
15.03.2026 | 79 Uwe Schultes, DL9UWE@darc.de (Draft) - Veröffentlichung der Dokumentation und der 3D-Druckdaten unter den

# Grundkonfiguration

# Zunächst ist hier der „Cell Count“ von 8 auf 4 Zellen

anzupassen und anschließend „OK“ anzuklicken.

# Danach ist die „Battery Capacity“ von 40Ah auf 20Ah

anzupassen und wieder „OK“ anklicken.
Die Grundkonfiguration ist damit abgeschlossen.

# Erläuterungen zu den weiteren Parametern erfolgen

später.

15.03.2026 | 80 Uwe Schultes, DL9UWE@darc.de (Draft) - Veröffentlichung der Dokumentation und der 3D-Druckdaten unter den

# Ausblick

15.03.2026 | 81 Uwe Schultes, DL9UWE@darc.de (Draft) - Veröffentlichung der Dokumentation und der 3D-Druckdaten unter den

# Was kann man noch hinzufügen?

# Der Akku kann durch weitere Baugruppen ergänzt werden, um die

Funktionalität auszubauen.

# Mögliche Ideen ✓Separate Baugruppe, so dass der Akku als regelbares Labornetzteil genutzt

werden kann. Dies kann z.B. recht günstig über ein Schaltnetzteil erfolgen. ✓Eine leistungsfähige LED für eine Notstrombeleuchtung.
✓Ein „Flashlight“ für Pannen.

# ✓Ein Hochstromadapter der zum Starten eines Motorrads oder eines PKW

genutzt werden kann.

15.03.2026 | 82 Uwe Schultes, DL9UWE@darc.de (Draft) - Veröffentlichung der Dokumentation und der 3D-Druckdaten unter den

# Fazit

15.03.2026 | 83 Uwe Schultes, DL9UWE@darc.de (Draft) - Veröffentlichung der Dokumentation und der 3D-Druckdaten unter den

# Fazit

# Mit dieser Anleitung kannst du dir einen sicheren und leistungsstarken LiFePo-

Akku selbst bauen.

# Beachte stets die Sicherheitsregeln und überprüfe regelmäßig den Zustand deines

Akkus.

# Anregungen gerne: dl9uwe@darc.de

# Viel Erfolg beim Nachbauen!

15.03.2026 | 84 Uwe Schultes, DL9UWE@darc.de (Draft) - Veröffentlichung der Dokumentation und der 3D-Druckdaten unter den

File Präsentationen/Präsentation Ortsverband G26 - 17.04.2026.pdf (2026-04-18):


# VORTRAG G26

# 12 V AKKU ALS SELBSTBAUPROJEKT

17.04.2026, DL9UWE

Kurzvorstellung G11...

# Eigenwerbung muss sein…

▪ Jeden 3. Freitag im Monat; OV Abend, Gäste sind herzlich willkommen!

▪ G11 in Leverkusen
▪ Etwa 160 Mitglieder
▪ Vorstand: Georg (DL3YAT), Ben (DO1BEN) und Martin (DH9FAL)

https://darc.de/g11

https://instagram.com/do1ben_darc_g11_leverkusen/

https://www.facebook.com/darclev/

Schaut mal rein, bei uns ist immer was los….

# Bei uns wird‘s nicht langweilig

Lizenzkurse für die N-,
E- und A-Klasse (*) | Morsekurs

Meshtastic und
Meshcore Team

"Basteln für Erwachsene"
oder "Nur löten macht
glücklich...."

Notfunk Team

Jährlicher Fieldday auf
Kump
http://www.kump-fieldcamp.de/

Jeden 3. Freitag im
Monat OV Abend

Viele Vorträge…

Jugendgruppe Werner-Heisenberg Gymnasium

Vereinszeitung
#CQ Leverkusen

# CQ Leverkusen


# Wie sind wir zu erreichen?

Art | Frequenz | Betriebsart
Relais DB0LEV | 70cm 439,1875 MHz (-7,6MHz) | FM, C4FM, FMN CTCSS 67Hz
Relais DB0LEV | 23cm 1298,650 MHz (-28MHz) | FM
Winlink Einstieg via DB0AIM | 438,150 MHz | VARA
OV-Frequenzen (2m) | 145,3625 MHz | FM
OV-Frequenz (70cm) | 433,575 MHz | FM

Die Frequenzen stehen auch auf der Homepage von G11

Nun zurück zum Akku...

# Es geschah an einem Selbstbauabend

Uwe
Sag mal, was hast du
Siegfried | denn da mitgebracht?
Ich habe mal mit ein paar
LiFePo‘s und einem BMS experimentiert. LiFePos benutze ich auch bei meiner PV-Anlage. | Uwe Das wäre doch mal was

Warum nicht?; Uwe; machen. Siegfried; Mal doch mal einen

| zum portablen
| Funkbetrieb und als
| Notstromversorgung.

Siegfried

| Cool, jetzt müssen wir
| uns mal überlegen, wie
| wir das Nachbaussicher

Vorschlag…..
Ichhabe doch den 3D
Drucker….

1

2

3

4

6

# Die Idee des Selbstbauakku reift

### ▪Die Rahmenbedingungen waren schnell gefunden

- 12 Volt
- Klein


- Leicht
- Transportierbar
- Leistungsfähig
- Kostengünstig
- Einsatz: Outdoor- / Notfunk- und portable Anwendung

# Die Idee des Selbstbauakku reift

- Mechanische Arbeiten sollten möglichst reduziert werden
- Nicht jeder OM hat Material und Werkzeug für einen Aufbau
- Lösung
- Gehäuse im 3D-Druck
- Nachbausicherheit deutlich verbessert
- Mechanische Aufwendungen auf ein Minimum reduziert
- Prototyp gedruckt mit PETG
- Gesamtdruckzeit für alle Bauteile des Gehäuses
- ca. 30 Stunden

# Die Kette

+ | + | =


Zelle | BMS | Gehäuse | Ergebnis


# Zelle

- Hersteller: EVE
- Lieferant: nkon
- Modell: EVE C40 40135 - 3,2V und 20AH
- Kosten: 8,25 € (je Zelle)
- Details:
- https://www.nkon.nl/de/eve-c40-40135-20ah-3-2v.html
- https://www.nkon.nl/de/amfile/file/download/file/170/product/5377/
- https://www.nkon.nl/de/amfile/file/download/file/1062/product/5377/

# Zelle

Beschreibung | Wert
Nennkapazität | 20000 mAh
Nennspannung | 3,2 V
Ladeschlussspannung | 3,65 V
Ladeschlussstrom | 1000 mA
Entladeschlussspannung | 2,5 V
Gewicht | 374 Gramm
Standardladestrom | 10000 mA
Standard-Entladestrom | 10000 mA
Maximaler kontinuierlicher Entladestrom | 60000 mA
Zyklen | 4000


# BMS

- Hersteller: Jikong
- Lieferant: AliExpress
- Kosten: 22-30 €
- Technologie: Aktiver Balancer
- Details:
- https://jikongbms.com/wp-content/uploads/2024/07/JIKONG-BMS-Product- (https://jikongbms.com/wp-content/uploads/2024/07/JIKONG-BMS-Product-introduction-P.pdf)introduction- (https://jikongbms.com/wp-content/uploads/2024/07/JIKONG-BMS-Product-introduction-P.pdf)P.pdf (https://jikongbms.com/wp-content/uploads/2024/07/JIKONG-BMS-Product-introduction-P.pdf)
- https://jikongbms.com/wp-content/uploads/2024/07/Jikong-BMS-JKBMS-Maintenance- (https://jikongbms.com/wp-content/uploads/2024/07/Jikong-BMS-JKBMS-Maintenance-instruction-of-Smart-BMS-with-Active-Balancer-V2.1.pdf)instruction- (https://jikongbms.com/wp-content/uploads/2024/07/Jikong-BMS-JKBMS-Maintenance-instruction-of-Smart-BMS-with-Active-Balancer-V2.1.pdf)of- (https://jikongbms.com/wp-content/uploads/2024/07/Jikong-BMS-JKBMS-Maintenance-instruction-of-Smart-BMS-with-Active-Balancer-V2.1.pdf)Smart- (https://jikongbms.com/wp-content/uploads/2024/07/Jikong-BMS-JKBMS-Maintenance-instruction-of-Smart-BMS-with-Active-Balancer-V2.1.pdf)BMS- (https://jikongbms.com/wp-content/uploads/2024/07/Jikong-BMS-JKBMS-Maintenance-instruction-of-Smart-BMS-with-Active-Balancer-V2.1.pdf)with- (https://jikongbms.com/wp-content/uploads/2024/07/Jikong-BMS-JKBMS-Maintenance-instruction-of-Smart-BMS-with-Active-Balancer-V2.1.pdf)Active- (https://jikongbms.com/wp-content/uploads/2024/07/Jikong-BMS-JKBMS-Maintenance-instruction-of-Smart-BMS-with-Active-Balancer-V2.1.pdf)Balancer- (https://jikongbms.com/wp-content/uploads/2024/07/Jikong-BMS-JKBMS-Maintenance-instruction-of-Smart-BMS-with-Active-Balancer-V2.1.pdf)V2.1.pdf (https://jikongbms.com/wp-content/uploads/2024/07/Jikong-BMS-JKBMS-Maintenance-instruction-of-Smart-BMS-with-Active-Balancer-V2.1.pdf)

# BMS


- Kennwerte

# BMS

- Problem ohne BMS
- Zellspannungsdrift
- Über- / Tiefentladung
- Thermisches Risiko
- Ohne Balancieren bestimmt
- Die schwächste Zelle die nutzbare Kapazität
- Die stärkste Zelle das Abschalt-Limit beim Laden

# BMS

- BMS-Aufgaben
- Zellspannungsüberwachung
- Balancing
- Überstrom- & Temperaturschutz


## Ohne BMS kein sicherer Betrieb!

# BMS

- Unterschiede passiver/aktiver Balancer
- Passiver Balancer
- Zellen werden über Widerstände leicht entladen
- überschüssige Energie wird als Wärme umgesetzt
- niedrigere Zellen laden währenddessen weiter auf
- Aktiver Balancer
- Energie wird von volleren Zellen aktiv auf leerere Zellen übertragen
- z.B. über DC-DC-Wandler oder Kondensator-Shuttles
- kaum Energieverlust als Wärme

# Gehäuse


# Ergebnis


# Details: der innere Aufbau


# Details: BMS montieren


# Details: Verdrahtung

Jikong BD6A8S10P; abgelegt werden.

B - bedeutet „Battery“ Minuspol

P - bedeutet „Power“ Minuspol

Die Anschlüsse B5-B8 werden nicht
benötigt und können gekürzt und mit
Schrumpfschlauch isoliert, im Gehäuse

# Details: Anschlussbox

- 3 x Anschlüsse (Bananenbuchsen)


- 3 x Powerpole Anschlüsse
- 3 x 15A Stecksicherungen
- 1 x 50A Hauptsicherung

# Die App


- Smartphone App für
- iPhone
- Android
- Verbindung via Bluetooth
- Konfiguration über Bluetooth
- Extrem umfangreiche
Konfiguration möglich
- Export eines Reports möglich
- Alle Features aufzuzählen, sprengt hier den Rahmen….

# Wer hat‘s erfunden?

- Alle 3D-Druckbauteile und Bauanleitung verfügbar
- Uwe, DL9UWE
- Umfangreiche Konfigurationsanleitung für den Akku
- Siegfried, DC7SB
- Wird gerade überarbeitet und nachgereicht

## https://github.com/schulteu

## Rückfragen gerne an dl9uwe@darc.de

# Ausblick

- Der Akku kann durch weitere Baugruppen ergänzt werden, um die Funktionalität auszubauen
- Mögliche Ideen
- Separate Baugruppe, so dass der Akku als regelbares Labornetzteil genutzt werden kann
- Dies kann z.B. recht günstig über ein Schaltnetzteil erfolgen
- Eine leistungsfähige LED für eine Notstrombeleuchtung
- Ein „Flashlight“ für Pannen
- Ein Hochstromadapter der zum Starten eines Motorrads oder eines PKW genutzt werden kann

Vielen Dank...

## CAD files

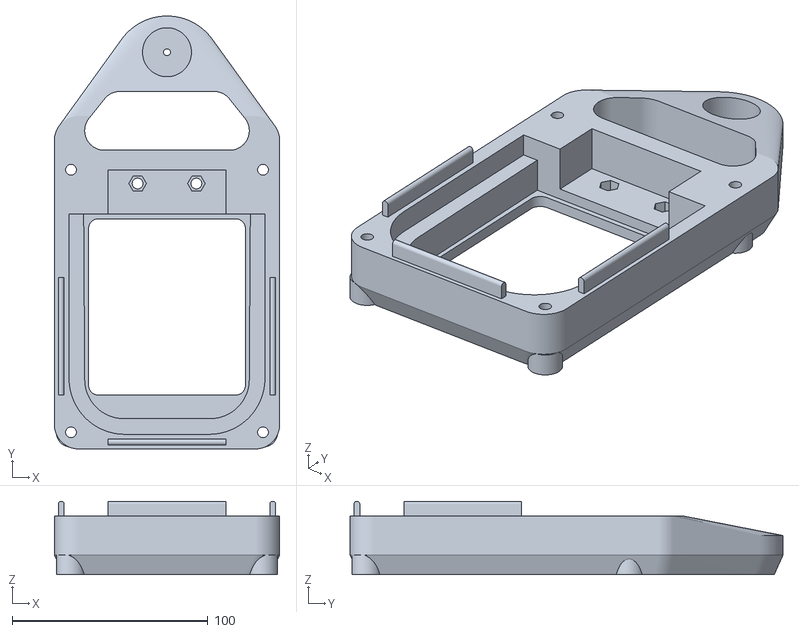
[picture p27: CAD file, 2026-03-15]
STL-Files/Seitenteil_mit_Anschlusskasten.stl
115.0 x 221.0 x 37.5

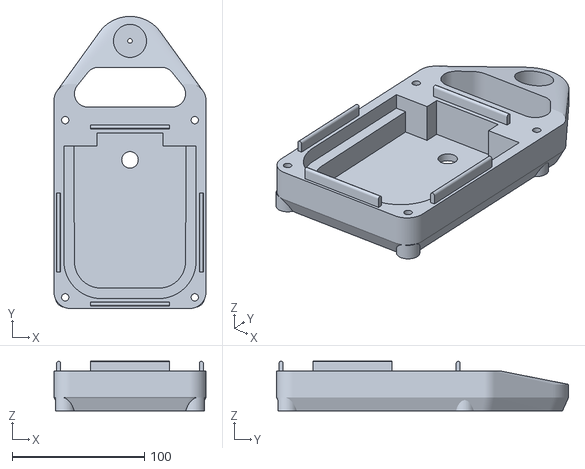
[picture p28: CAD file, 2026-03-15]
STL-Files/Seitenteil_mit_Schalter.stl
115.0 x 221.0 x 37.5

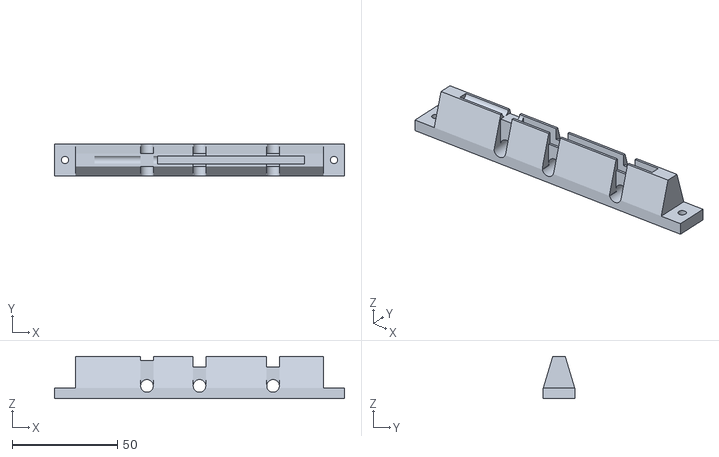
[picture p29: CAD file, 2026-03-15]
STL-Files/Verstrebung_Innenteil_v3.stl
138.0 x 15.0 x 20.0

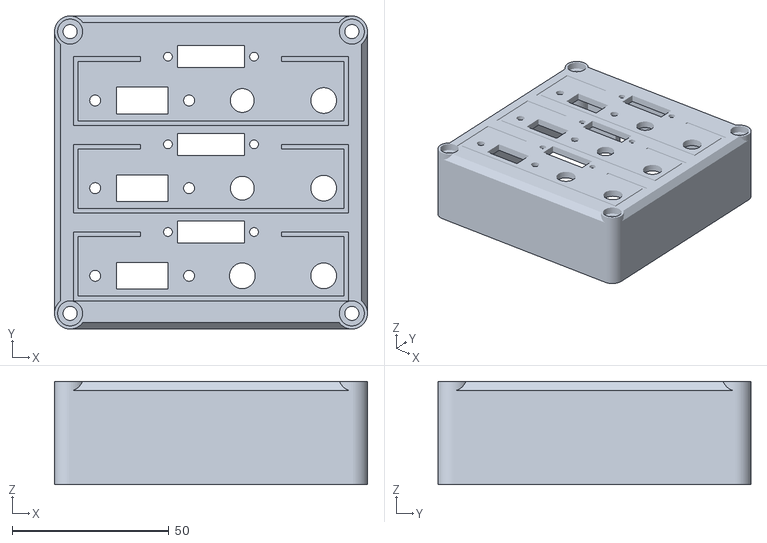
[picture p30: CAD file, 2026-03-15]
STL-Files/Anschlusskasten.stl
100.0 x 100.0 x 33.0

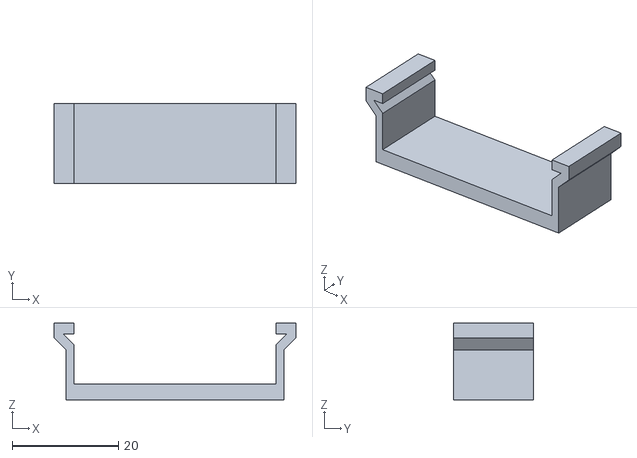
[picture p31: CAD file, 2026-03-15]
STL-Files/Powerpole_Adapter_Clip.stl
45.5 x 15.0 x 14.4

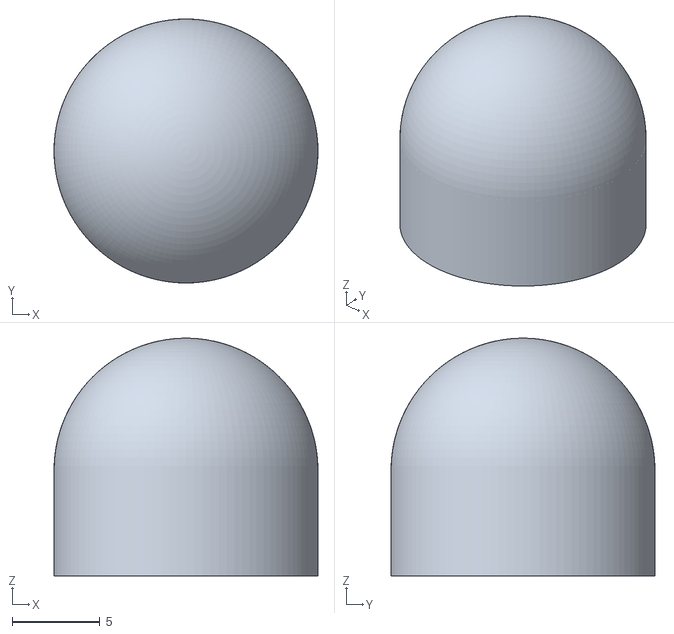
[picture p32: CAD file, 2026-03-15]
STL-Files/Akku_Abdeckkappen_v2.stl
15.0 x 15.0 x 13.5

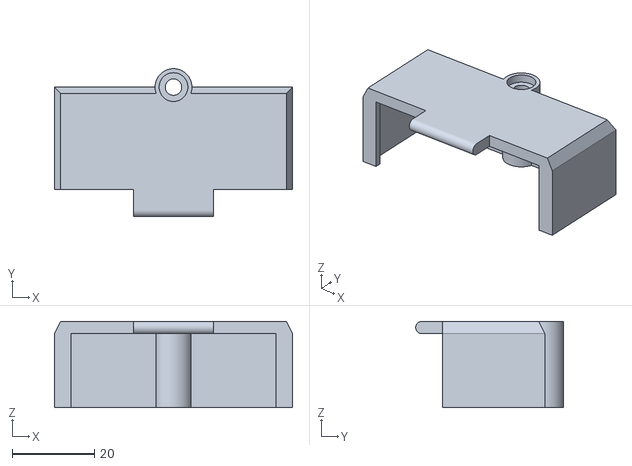
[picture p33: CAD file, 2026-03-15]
STL-Files/Abdeckung_Sicherung.stl
58.0 x 36.0 x 21.0

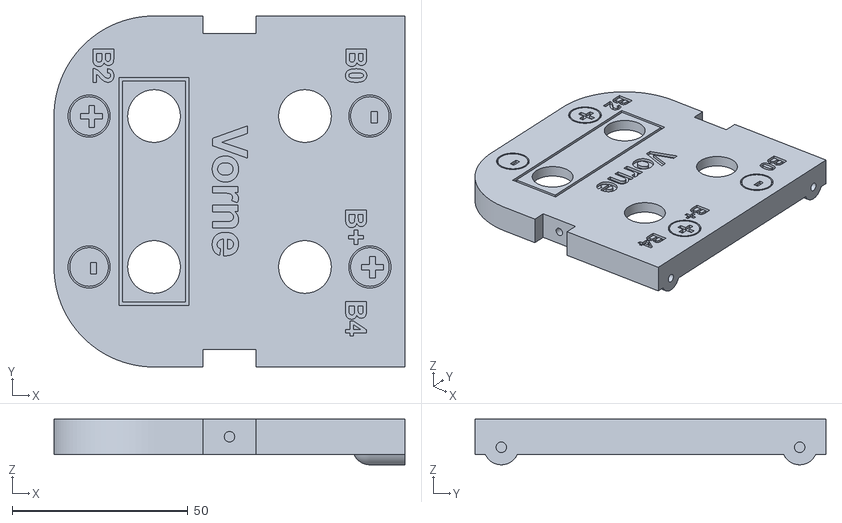
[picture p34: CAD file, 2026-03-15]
STL-Files/Innenteil_Vorne.stl
100.0 x 100.0 x 13.0

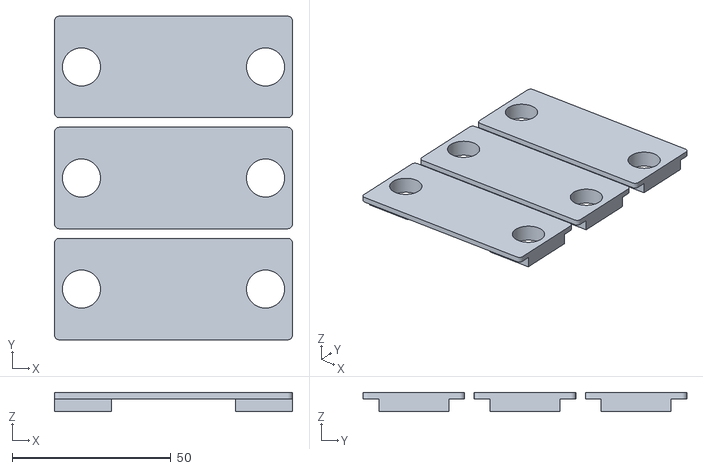
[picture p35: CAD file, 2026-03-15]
STL-Files/3 x Adapter_BMS_v2.stl
75.0 x 102.0 x 6.00

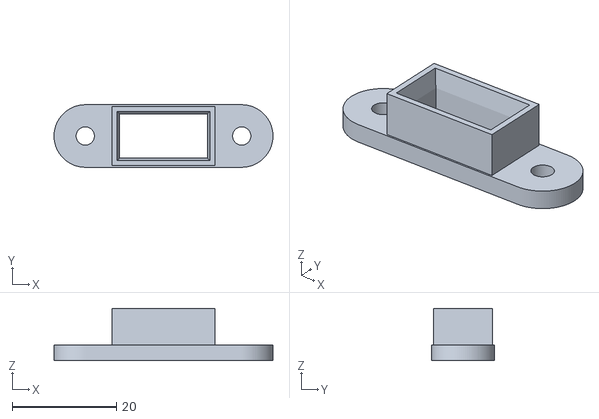
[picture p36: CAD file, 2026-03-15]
STL-Files/Powerpole_Kragen.stl
42.0 x 12.0 x 10.0

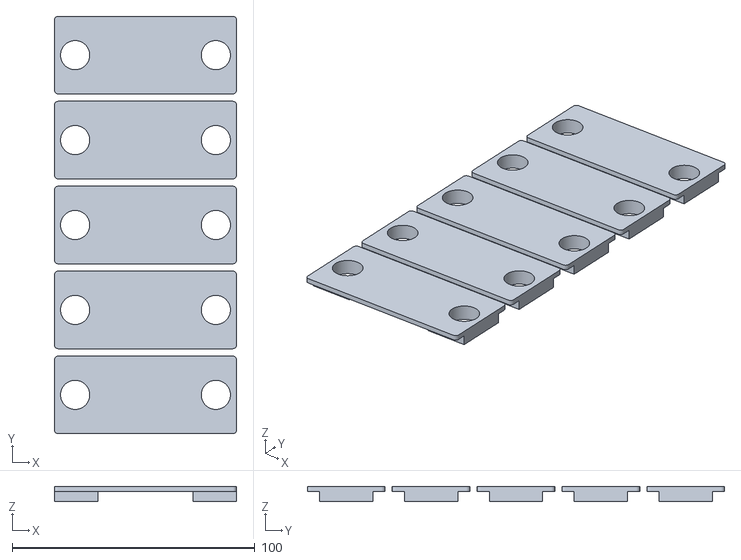
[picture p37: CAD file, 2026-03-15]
STL-Files/Adapter_BMS_v2.stl
75.0 x 172.0 x 6.00

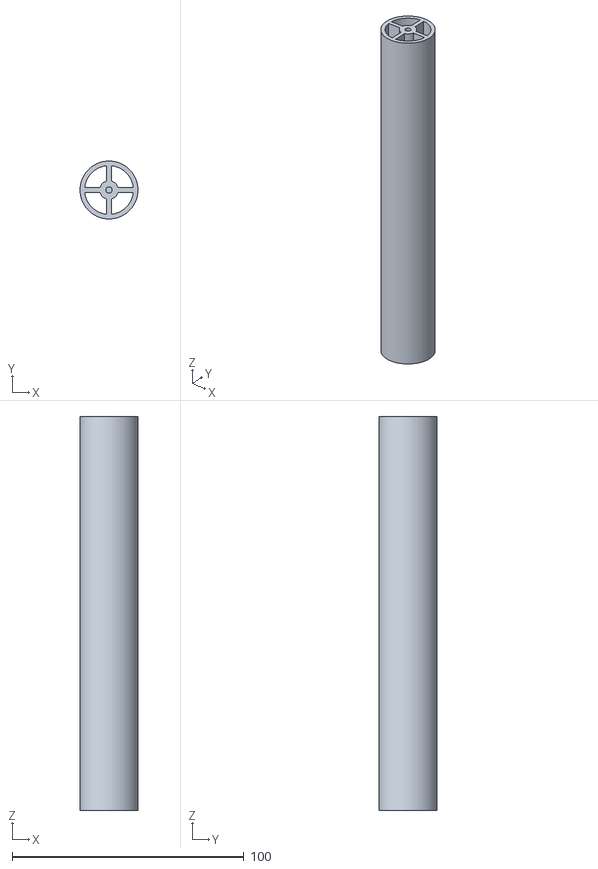
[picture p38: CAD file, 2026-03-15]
STL-Files/Griff.stl
25.0 x 25.0 x 170.0

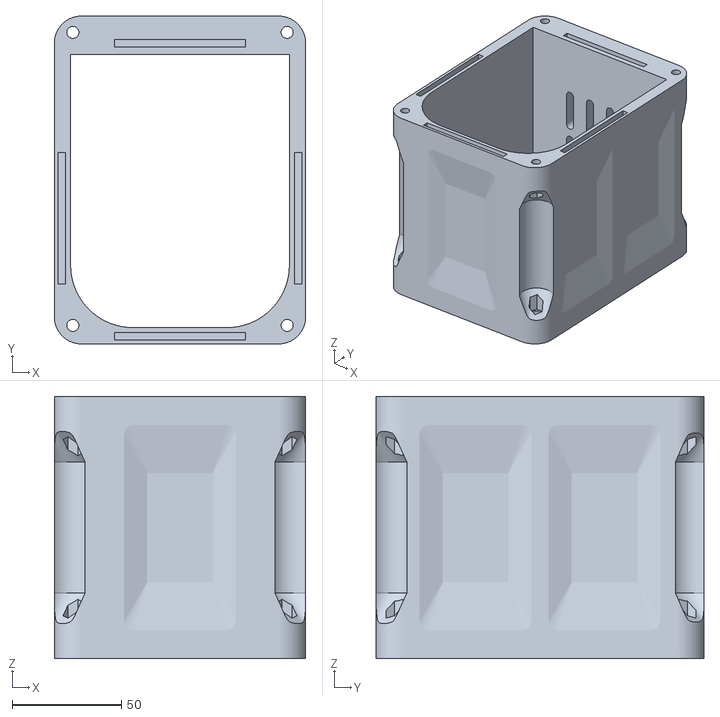
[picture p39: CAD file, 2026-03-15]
STL-Files/Mittelteil_Aussen.stl
115.0 x 150.0 x 120.0

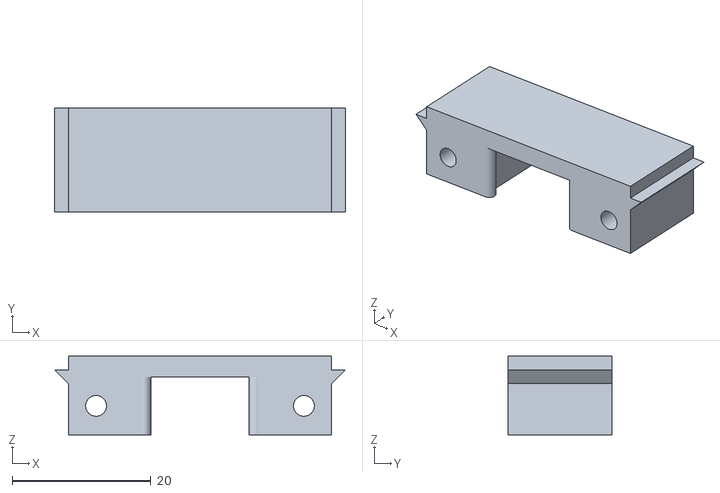
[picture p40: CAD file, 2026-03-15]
STL-Files/Powerpole_Einsatz.stl
42.0 x 15.0 x 11.4

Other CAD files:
STL-Files/Innenteil_Hinten.stl

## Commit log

2026-03-15 Initiale Erstellung
    [3 x Adapter_BMS_v2.stl, AMP_Halter.stl, Abdeckung_Sicherung.stl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]
2026-03-15 GitHub Link der Dokumentation hinzugfügt.
2026-03-15 AMP Halter entfernt.
    [AMP_Halter.stl]
